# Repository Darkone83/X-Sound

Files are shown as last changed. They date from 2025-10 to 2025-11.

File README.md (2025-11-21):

<p align="center">
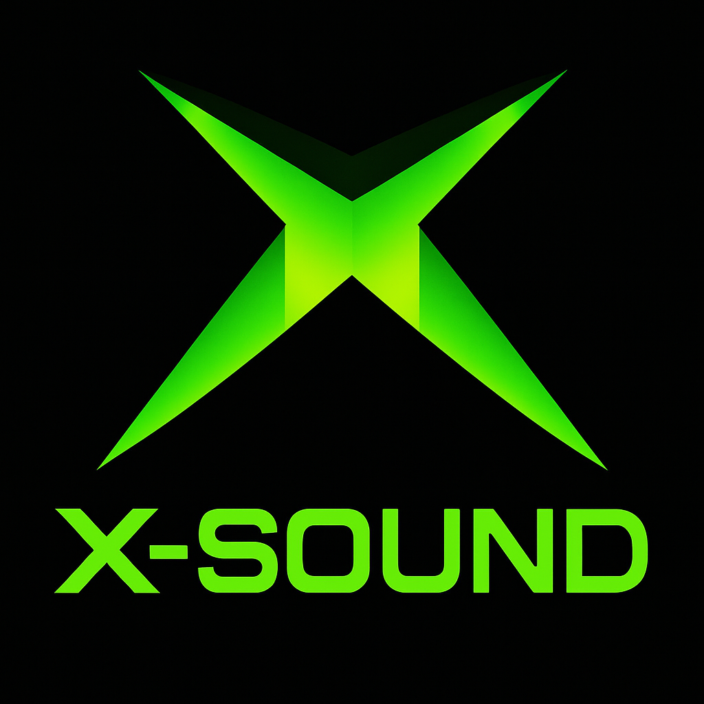
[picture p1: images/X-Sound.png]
  
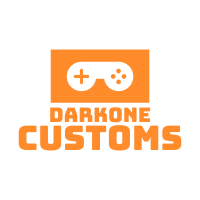
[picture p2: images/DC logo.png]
  
</p>

<p align="center">
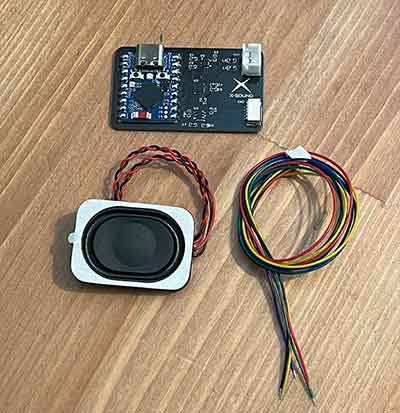
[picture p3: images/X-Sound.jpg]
  
</p>



# X-Sound

Ever wanted an Xbox startup sound? X-Sound brings it to the OG XBOX, with a compact ESP32-S3 module that adds custom **boot** and **eject** sounds to your original Xbox. No more silent power-ups – now you get that nostalgic audio experience with modern web-based control.

Built by **Darkone83 / Darkone Customs**.

---

## What it does

**Plays the sounds you remember**
- Triggers `/boot.mp3` automatically when you power on
- Plays `/eject.mp3` when you hit the eject button
- Works with .mp3 files (96-128kbps, 44.1kHz mono, keep them under 30 seconds)

**Easy file management through your browser**
- Upload, delete, and test audio files from any device on your network
- Built-in volume control and playback testing
- No need to fiddle with SD cards or complex file transfers

**Smart Wi-Fi setup**
- First boot creates a setup network you connect to
- Configure once, then it automatically connects to your home Wi-Fi
- Access everything at `http://xsound.local`

**Clean installation**
- Uses Xbox's own 3.3V rail to control power switching
- Only draws power when your Xbox is actually on

---

## Get one

Full kit available at: <a href="https://www.darkonecustoms.com/store/p/x-sound">Darkone Customs</a>

---

## Building the firmware

#### Web Flasher: 

Want to customize or build your own? Here's what you need:

1. Grab the project files and open in Arduino IDE
2. Install the libraries listed below
3. Set up your board configuration (see settings table)
4. Upload `X-Sound.ino` to your ESP32-S3
5. Connect to the `X-Sound-Setup` network that appears
6. Enter your home Wi-Fi details
7. Once it reboots, go to `http://xsound.local`
8. Upload your `boot.mp3` and `eject.mp3` files

---

## Libraries you'll need

Install these through the Arduino IDE Library Manager:

- **ESP Async WebServer** (me-no-dev)
- **AsyncTCP** (me-no-dev)
- **ESP8266Audio** (Earle Philhower)

> Note: Make sure you're using `AudioFileSourceFS` instead of `AudioFileSourceSPIFFS` for ESP32 compatibility.

---

## Arduino IDE setup

| Setting | Value |
|---|---|
| **Board** | ESP32S3 Dev Module |
| **Upload Speed** | 921600 |
| **Flash Freq** | 80 MHz |
| **PSRAM** | Disabled |
| **Partition Scheme** | 1.2 MB App / 1.5 MB SPIFFS |
| **Core Version** | ESP32 3.0.7 (Recommended) |

---

## Connecting to your Xbox

### Xbox connector pinout (CN2)
| Pin | What it is |
|---|---|
| 1 | 5V |
| 2 | GND |
| 3 | X3V3 (3.3V detection) |
| 4 | GND |
| 5 | EJECT (goes low when pressed) |

---

## Installation points

> ⚠️ **Unplug your Xbox first!**

Here's where to tap into your Xbox motherboard:

**Ground (GND):** Any solid ground point works. The LPC header ground is convenient, or the DVD connector ground.

**5V:** Grab this from the LPC connector or the DVD power plug's 5V line.

**3.3V:** Connect to the 3.3V rail on the LPC connector (pin 3). This tells X-Sound when your Xbox is actually powered up.

**EJECT:** Tap into the eject signal from the front panel connector or find the trace on the mainboard.

Keep your wires short and neat. Twisted pairs help reduce interference if you're having audio issues.

---

## Getting connected

**First time setup:**
1. Power up and look for the `X-Sound-Setup` Wi-Fi network
2. Connect with your phone or computer
3. The setup page should open automatically (or go to `192.168.4.1`)
4. Enter your home Wi-Fi name and password
5. Hit save and wait for it to reboot

**Normal use:**
- Visit `http://xsound.local` from any device on your network
- Use the File Manager to upload your sounds
- Test playback and adjust volume as needed

---

## When things go wrong

| Problem | Try this |
|---|---|
| **Can't reach the web page** | Check that you're going to `xsound.local` and look at the LED: Green = connected, Red = no Wi-Fi |
| **No sound plays** | Make sure you have `/boot.mp3` and `/eject.mp3` uploaded and they're proper MP3 files |
| **Audio sounds terrible** | Turn down the volume or re-encode your files as 44.1kHz mono at 128kbps |
| **Eject button doesn't work** | Double-check your GPIO9 connection and make sure the Xbox signal is wired correctly |
| **LED blinks red rapidly** | File playback error - check that your MP3 is 96-128kbps, 44.1kHz mono, under 30 seconds |
| **Won't power on at all** | Verify the 3.3V connection. Without it, X-Sound won't boot |

---

## Credits

**Concept:** Darkone83 / LD50 II   
**Hardware design:** Darkone83  
**Firmware:** Darkone83  
**Libraries we couldn't live without:**
- ESP8266Audio by Earle Philhower
- ESP Async WebServer / AsyncTCP by me-no-dev

---

## How it all works

```
┌────────────────────────────────────────────────────┐
│                   ESP32-S3 ZERO                    │
│                                                    │
│  GPIO12 ────────► BCLK ───────► MAX98357A (I²S AMP)│
│  GPIO11 ────────► LRCLK ─────►                     │
│  GPIO10 ────────► DOUT ──────► DIN                 │
│  GPIO9  ◄───────► EJECT (Xbox CN2 Pin 5)           │
│                                                    │
│  3.3V (out) ─────► TPS22918 EN (ON pin)            │
│  5V (in)  ───────► TPS22918 VIN                    │
│  5VEN (switched) ─► MAX98357A VDD                  │
│                                                    │
│  SPIFFS: /boot.mp3 /eject.mp3                      │
│  Web: http://xsound.local/files                    │
└────────────────────────────────────────────────────┘

   CN2 (Xbox Front Panel)
   ┌─────┬────────────┐
   │ 1   │ 5V         │
   │ 2   │ GND        │
   │ 3   │ X3V3 Detect│
   │ 4   │ GND        │
   │ 5   │ EJECT      │
   └─────┴────────────┘
```

---

**X-Sound** — Because your Xbox deserves to sound as good as it looks.  
© 2025 **Darkone83 / Darkone Customs**

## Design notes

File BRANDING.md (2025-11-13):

# X-Sound Branding Requirements  
**Darkone Customs / Darkone83**

This document defines the branding rules for all derivatives, forks, and
redistribution of the X-Sound hardware and software.

---

## 1. Branding Must Remain Intact
All Darkone Customs and Darkone83 branding MUST remain untouched in:

- PCB silkscreens  
- Schematics  
- 3D models  
- Firmware UI elements  
- Documentation  
- Images/renderings  
- Marketing material derived from the project  

Branding includes (but is not limited to):

- "Darkone83"
- "Darkone Customs"
- "Team Resurgent"
- Logos, icons, and symbol marks used in PCB art

Removal, modification, shrinking, obscuring, or overwriting of these elements
is **not permitted**.

---

## 2. Required Attribution
Any forks, derivatives, or commercial uses **must clearly state**:

**"Original Design by Darkone83 / Darkone Customs"**

This must appear in:

- README files  
- Product listings (if sold)  
- Printed or digital documentation  
- Any derivative hardware silkscreens  

---

## 3. Additional Branding (Allowed)
You may add:

- Your own maker mark  
- Your logo  
- Version codes  
- Batch identifiers  
- Assembly information  

…as long as the original branding remains **visible and unaltered**.

---

## 4. Use of Name and Logos
You *may not* imply that Darkone Customs endorses or supports derivative works.

You *may not* use the logos or branding for unrelated projects unless granted
permission.

---

## 5. Approved Files
Official versions of logos, silkscreen assets, and identifiers will be included
under:

```
/branding/
```

You must use the provided official versions if they exist.

---

## 6. Reporting Violations
If you find a fork, derivative, or commercial listing violating these rules,
open an Issue on the repository with links and details.

---

This branding policy protects the identity and authorship of the X-Sound project
and all associated Darkone Customs work.

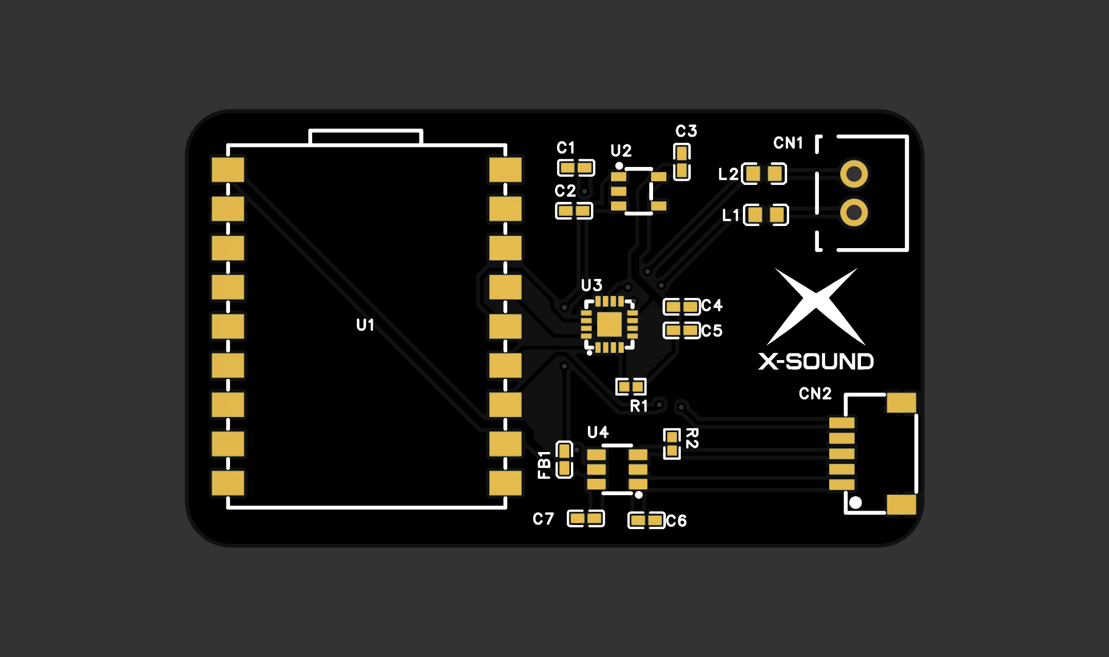
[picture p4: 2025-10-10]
images/PCB_Front.png

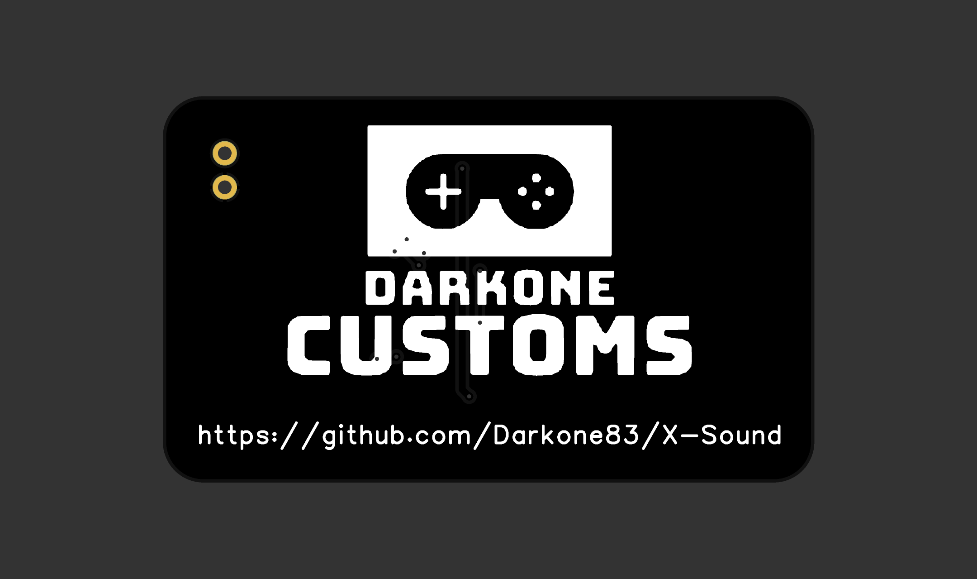
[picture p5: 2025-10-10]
images/PCB_Back.png

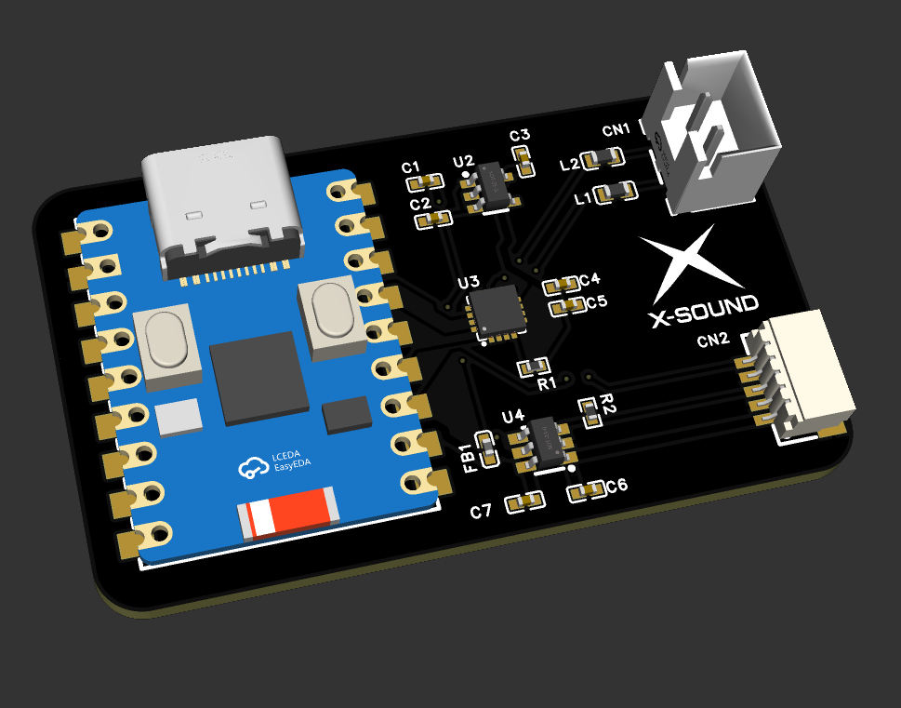
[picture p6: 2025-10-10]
images/3D Front.png

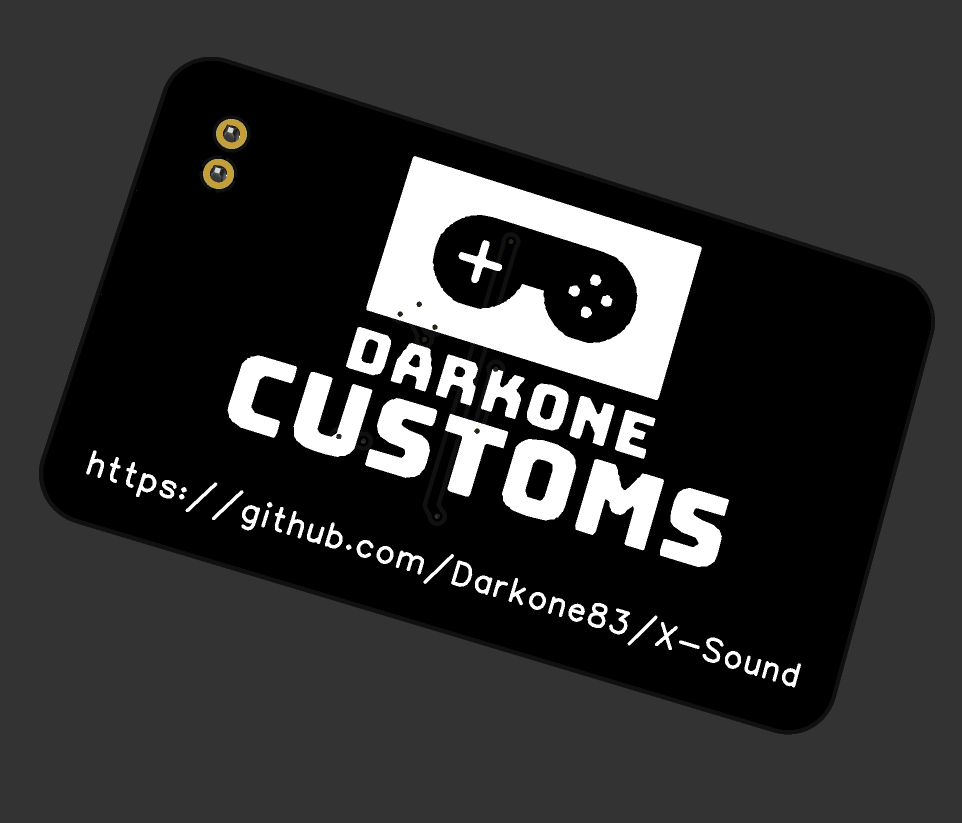
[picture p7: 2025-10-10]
images/3D Back.png

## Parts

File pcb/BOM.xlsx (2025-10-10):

No. | Quantity | Comment | Designator | Footprint | Value | Manufacturer Part | Manufacturer | Supplier Part | Supplier
1 | 2 | 10uF | C1,C4 | C0402 | 10uF | CL05A106MQ5NUNC | SAMSUNG(三星) | C15525 | LCSC
2 | 4 | 1uF | C2,C3,C6,C7 | C0402 | 1uF | CL05A105KO5NNNC | SAMSUNG(三星) | C29266 | LCSC
3 | 1 | 100nF | C5 | C0402 | 100nF | CC0402KRX7R5BB104 | YAGEO(国巨) | C541406 | LCSC
4 | 1 | B2B-XH-A(LF)(SN) | CN1 | CONN-TH_B2B-XH-A-LF-SN |  | B2B-XH-A(LF)(SN) | JST | C158012 | LCSC
5 | 1 | XDWF-0910-05P | CN2 | CONN-SMD_XDWF-0910-05P |  | XDWF-0910-05P | LX(连欣科技) | C7527620 | LCSC
6 | 1 | CBM100505U201T | FB1 | L0402 |  | CBM100505U201T | FH(风华) | C394402 | LCSC
7 | 2 | BLM18SG331TN1D | L1,L2 | L0603 |  | BLM18SG331TN1D | muRata(村田) | C88989 | LCSC
8 | 1 | 680kΩ | R1 | R0402 | 680kΩ | FRC0402F6803TS | FOJAN(富捷) | C2909377 | LCSC
9 | 1 | 100kΩ | R2 | R0402 | 100kΩ | RC0402FR-07100KL | YAGEO(国巨) | C60491 | LCSC
10 | 1 | ESP32-S3-Zero | U1 | COMM-SMD_18P-P2.54-L23.5-W18.0-TL |  | ESP32-S3-Zero |  | C9900152785 | LCSC
11 | 1 | XC6227C331MR-G | U2 | SOT-25-5 |  | XC6227C331MR-G | TOREX(特瑞仕) | C216640 | LCSC
12 | 1 | MAX98357AETE+T | U3 | TQFN-16_L3.0-W3.0-P0.50-BL-EP1.5 |  | MAX98357AETE+T | ADI(亚德诺)/MAXIM(美信) | C910544 | LCSC
13 | 1 | TPS22918DBVR | U4 | SOT-23-6_L2.9-W1.6-P0.95-LS2.8-BR |  | TPS22918DBVR | TI(德州仪器) | C131941 | LCSC

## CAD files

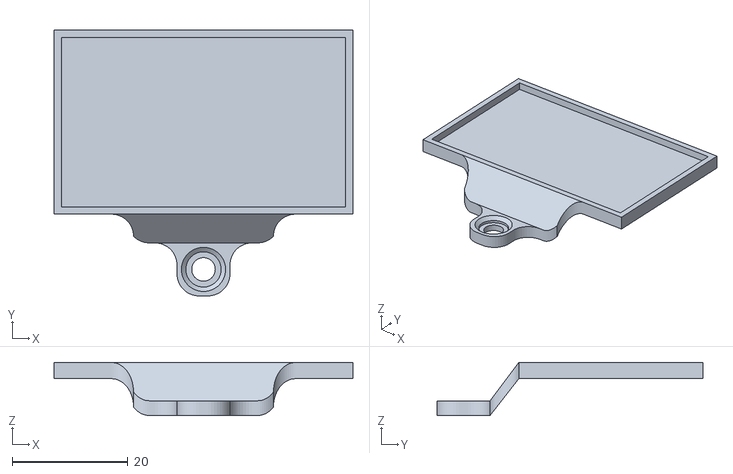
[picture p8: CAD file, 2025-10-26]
STL/X Sound Mount v1.stl
51.6 x 45.8 x 9.14

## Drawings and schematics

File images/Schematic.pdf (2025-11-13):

# IO7 10 IO8 11 IO9 12 IO10 13 IO11 14 IO12 15 IO13 16 RX 17 TX 18

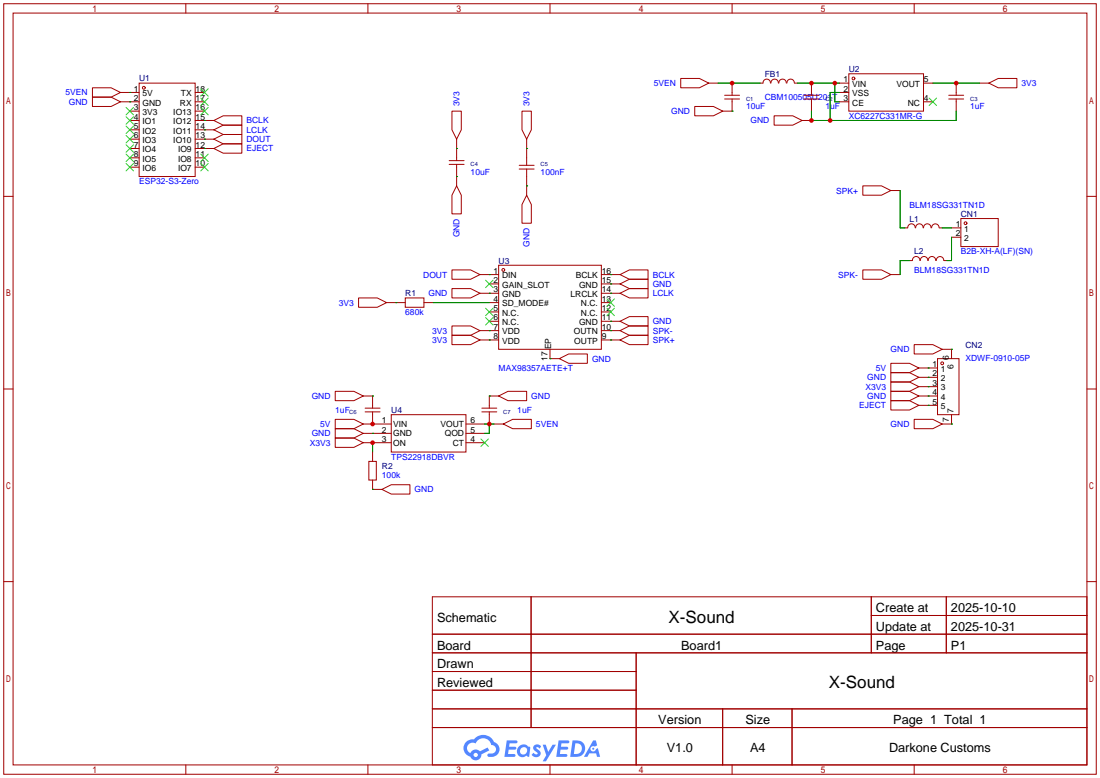
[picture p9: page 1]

OUTN 10 GND 11 N.C. 12 N.C. 13 LRCLK 14 GND 15 BCLK 16

Schematic | X-Sound | Create at | 2025-10-10

Update at | 2025-10-31

Board | Board1 | Page | P1
Drawn | | X-Sound
Reviewed

Version | Size | Page 1 Total 1
V1.0 | A4 | Darkone Customs

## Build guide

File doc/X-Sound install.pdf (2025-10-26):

# X-Sound Usage and Installation

Hardware installation:

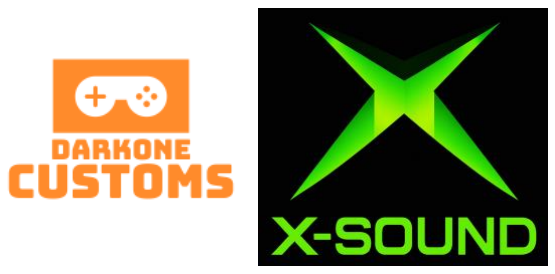
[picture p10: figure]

X-Sound requires the following connections:

5V
GND
3.3V
Eject

3 of the 4 signals can be tapped from the XBOX’s LPC header for ease of installation. As wiring harness colors may not be standardized here is the pinout of CN2:

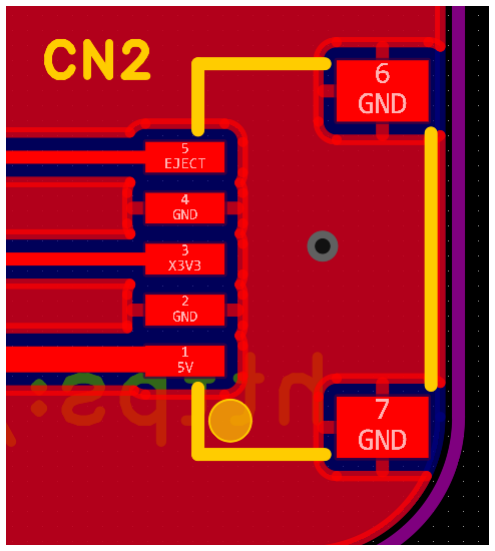
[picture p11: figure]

XBOX LPC header:

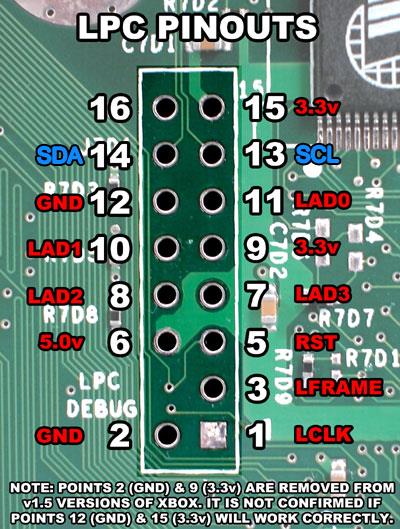
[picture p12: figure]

For eject, it's recommended to tap this from the back of the XBOX front panel, as it has ample routing and is easiest to access>

Eject Solder Point:

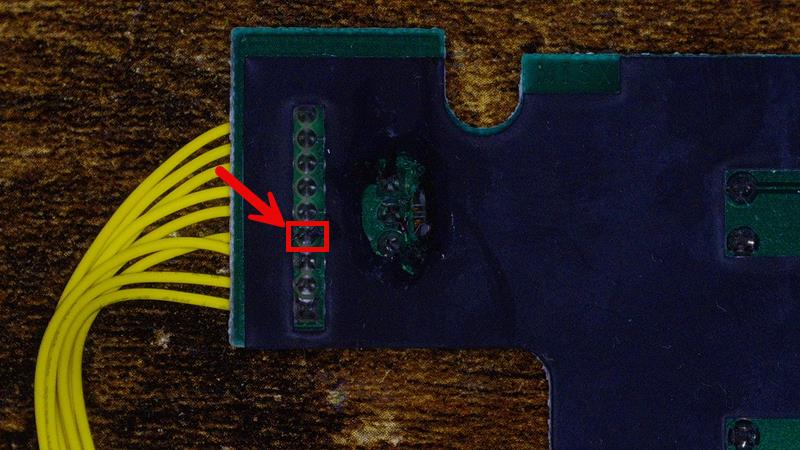
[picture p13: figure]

Example Routing:

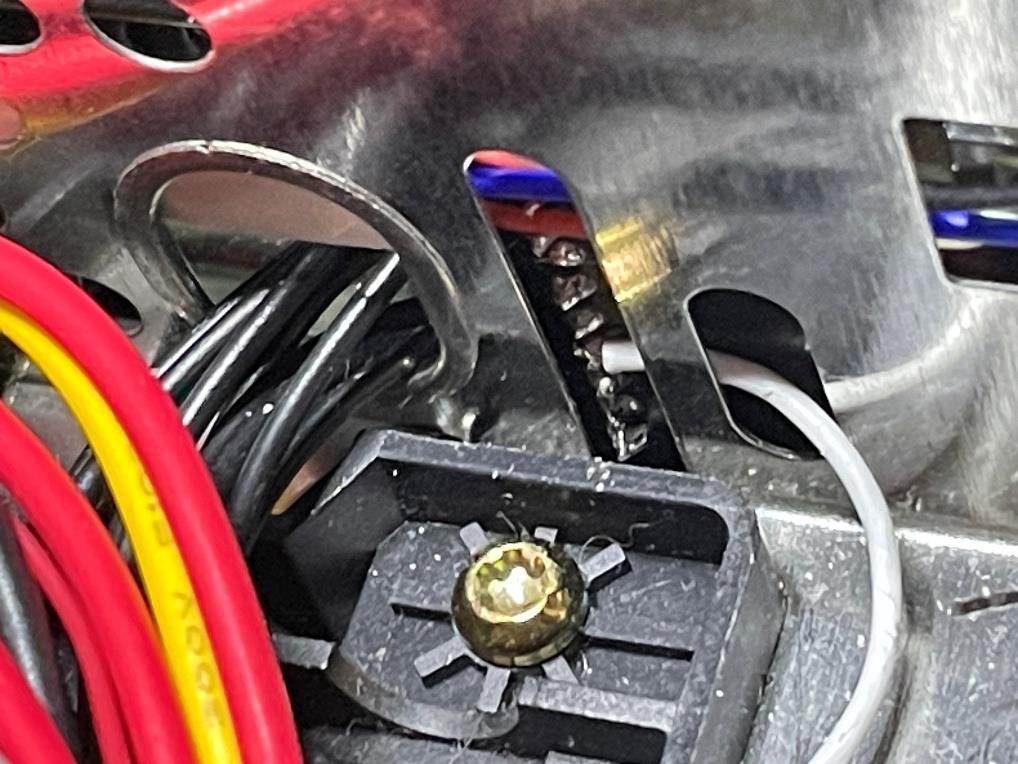
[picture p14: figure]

Finally connect your speaker

Recommended placement for X-Sound can vary by the installation; you can download the STL from the GitHub (https://github.com/Darkone83/X-Sound/blob/main/STL/X%20Sound%20Mount%20v1.stl) repo and opt for a mounted installation (recommended) or mount it to the inside of your XBOX. Ideally, you want the speaker and X-Sound mounted to non-conductive surfaces.

First Boot / Setup:

After installation on first power-up, X-Sound’s LED will go white, then blink purple for a second, then go to flashing red. Don’t panic, this is normal and simply means boot.mp3 is not found. To get started, connect X-Sound to choose a WiFi network ( WiFi is not strictly required but is recommended).

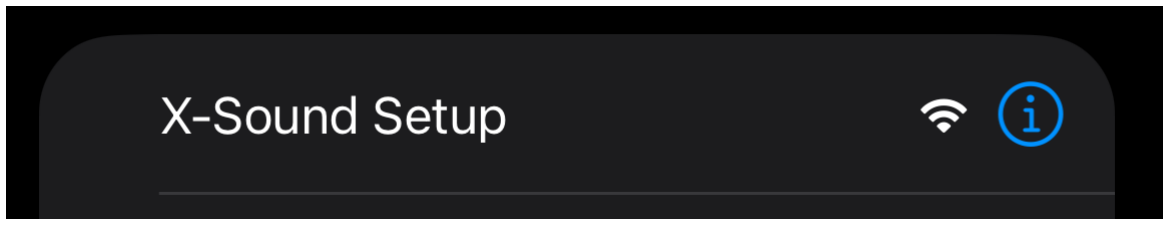
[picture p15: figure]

Once connected, you will be at the Configuration screen. Start by connecting to your WiFi network of choice

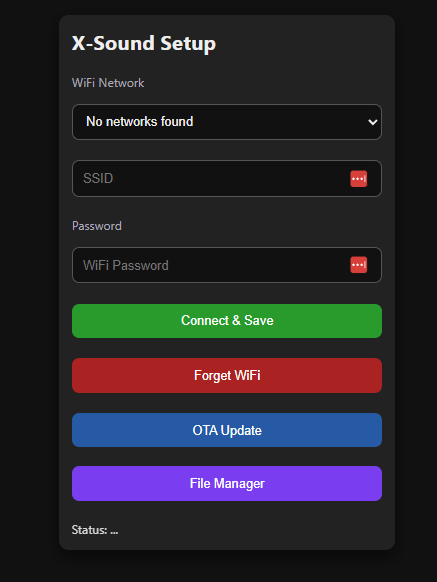
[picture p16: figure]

Once you have selected your network, click on Connect & Save. Once connected your X-Sound is accessible from http://xsound.local.

Sound Configuration:

X-Sound at the time of writing supports .mp3 files. Its suggested your files are 96 – 128 kbps and in mono, stereo can be put on X-Sound but X-Sound only currently supports mono playback. For your boot sounds its recommended to keep it to less than 1 minute as you will only have 1.5mb for both boot and eject sounds.

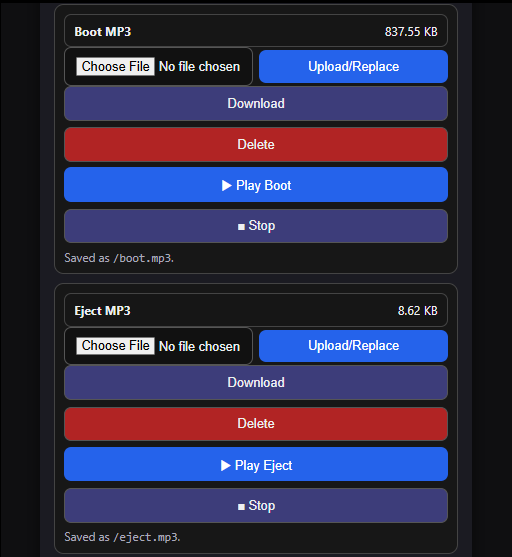
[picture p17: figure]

For both boot and eject, the process is exactly the same: Choose your file, then click Upload/Replace. X-Sound will rename the file for you, so no need to change the name beforehand.

The UI also gives you a few additional file management features such as: Downloading your currently saved sound, deleting your sound, playing your sound from the WebUI, and stopping your Sound from the WebUI.

Setting Volume:

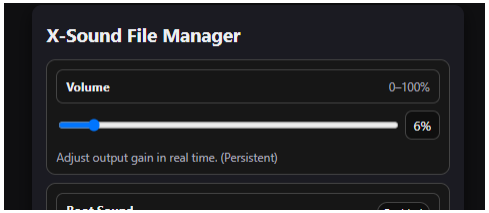
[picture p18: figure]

Simply drag the slider to your desired volume level X-Sound will remember your setting and apply it instantly. It will also remember this for every boot.

Additional options:

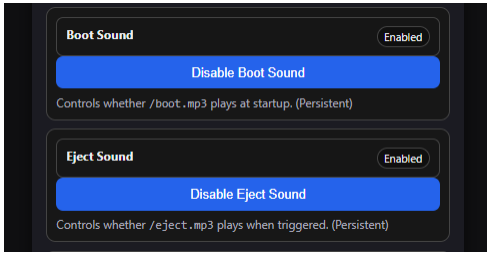
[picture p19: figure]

X-Sound does give you the ability to disable boot and eject so theirs no need to disconnect anything.

LED Statuses:

X-Sound has a few different LED statuses. Here's what they mean.

White = Booting
Green = Connected to WiFi
Red (solid) = Unable to Connect to WiFi
Purple (blinking) = WiFi portal mode
Magenta (blinking) = Currently playing a sound (will trigger on boot or eject) Red (fast flash) = No boot or eject.mp3 found

Troubleshooting:

Issue | Solution
No web page | Retry http://xsound.local or check LED status — Green = Wi-Fi connected, Red = no Wi-Fi
No audio | Verify /boot.mp3 & /eject.mp3 exist and are valid MP3s
Distortion | Lower volume or re-encode audio as 44.1 kHz mono @128 kbps
Eject not working | Check GPIO9 pull-up and Xbox signal polarity
Fast blinking red LED | Error with file playback, ensure file is the proper format (MP3 96 -128kpbs 44.1kHz mono under 30s)

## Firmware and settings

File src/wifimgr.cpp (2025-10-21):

#include "wifimgr.h"
#include <WiFi.h>
#include <ESPAsyncWebServer.h>
#include <Preferences.h>
#include <DNSServer.h>
#include "led_stat.h"
#include <vector>
#include <algorithm>
#include "esp_wifi.h"
#include <Update.h>  // OTA

// Single global server used by the whole project
static AsyncWebServer server(80);

namespace WiFiMgr {

static String ssid, password;
static Preferences prefs;
static DNSServer dnsServer;
static std::vector<String> lastScanResults;

enum class State { IDLE, CONNECTING, CONNECTED, PORTAL };
static State state = State::IDLE;

static int connectAttempts = 0;
static const int maxAttempts = 10;  // Reduced from 50 for faster fallback
static unsigned long lastAttempt = 0;
static unsigned long retryDelay = 3000;  // Increased from 2500ms

// Ensure portal routes are only added once (so we don't need server.reset()).
static bool portalRoutesAdded = false;
static bool serverStarted = false;

static bool dnsServerStarted = false;

AsyncWebServer& getServer() {
  return server;
}

// ---------------- WiFi cred storage ----------------
static void loadCreds() {
  prefs.begin("wifi", true);
  ssid = prefs.getString("ssid", "");
  password = prefs.getString("pass", "");
  prefs.end();
}

static void saveCreds(const String& s, const String& p) {
  prefs.begin("wifi", false);
  prefs.putString("ssid", s);
  prefs.putString("pass", p);
  prefs.end();
}

static void clearCreds() {
  prefs.begin("wifi", false);
  prefs.remove("ssid");
  prefs.remove("pass");
  prefs.end();
}

// --------------- AP/Portal helpers -----------------
static void setAPConfig() {
  WiFi.softAPConfig(
    IPAddress(192, 168, 4, 1),
    IPAddress(192, 168, 4, 1),
    IPAddress(255, 255, 255, 0)
  );
}

// ===== OTA HTML (progress + client-driven reboot) =====
static const char OTA_PAGE[] PROGMEM = R"html(
<!DOCTYPE html><html><head><meta charset="utf-8">
<meta name="viewport" content="width=device-width,initial-scale=1,viewport-fit=cover">
<title>OTA Update</title>
<style>
  :root{--bg:#111;--card:#222;--ink:#EEE;--mut:#AAB;--btn:#2563eb;--ok:#2ea043;--err:#d32}
  *{box-sizing:border-box} html,body{height:100%}
  body{background:var(--bg);color:var(--ink);font-family:system-ui,Segoe UI,Roboto,Arial;margin:0}
  .wrap{min-height:100%;display:flex;align-items:center;justify-content:center;padding:env(safe-area-inset-top) 12px env(safe-area-inset-bottom)}
  .box{width:100%;max-width:520px;margin:16px auto;background:var(--card);padding:18px 16px;border-radius:12px;box-shadow:0 8px 20px #0008}
  h2{margin:0 0 12px}
  .row{display:grid;grid-template-columns:1fr;gap:10px}
  input[type=file],button{width:100%;margin:.25rem 0;padding:.7rem .8rem;border-radius:9px;border:1px solid #555;background:#111;color:var(--ink);font-size:1rem}
  button{background:var(--btn);border:0;color:#fff;cursor:pointer}
  .status{margin-top:10px;color:var(--mut)}
  .bar{height:12px;background:#0c1222;border:1px solid #334;border-radius:999px;overflow:hidden}
  .fill{height:100%;width:0%}
  .ok{background:linear-gradient(90deg,#28a745,#3ddc84)}
  .up{background:linear-gradient(90deg,#4c7cff,#7aa4ff)}
  .err{background:linear-gradient(90deg,#d32,#f55)}
  .msg{margin-top:8px;font-size:.95rem}
</style></head>
<body>
<div class="wrap">
  <div class="box">
    <h2>OTA Update</h2>
    <div class="row">
      <input id="fw" type="file" accept=".bin,.bin.gz">
      <button id="go">Upload & Flash</button>
      <div class="bar"><div id="fill" class="fill up"></div></div>
      <div id="msg" class="msg">Select a firmware <code>.bin</code> (or <code>.bin.gz</code>) and click "Upload & Flash".</div>
      <div class="row">
        <button onclick="location.href='/'">⟵ Back to WiFi Setup</button>
        <button onclick="location.href='/files'">File Manager</button>
        <button onclick="reboot()" style="background:#a22">Reboot</button>
      </div>
      <div id="status" class="status"></div>
    </div>
  </div>
</div>
<script>
(function(){
  const fw   = document.getElementById('fw');
  const btn  = document.getElementById('go');
  const fill = document.getElementById('fill');
  const msg  = document.getElementById('msg');
  const status = document.getElementById('status');

  function setFill(p, cls){
    fill.style.width = (Math.max(0,Math.min(100,p))|0) + '%';
    fill.className = 'fill ' + (cls||'up');
  }
  function reboot(){
    fetch('/reboot',{method:'POST'}).catch(()=>0);
    setTimeout(()=>location.reload(), 2500);
  }
  function pingUntilUp(path, cb){
    let tries = 0;
    const t = setInterval(()=>{
      fetch(path, {cache:'no-store'}).then(r=>{ if (r.ok) { clearInterval(t); cb(true); } })
      .catch(()=>{});
      if (++tries > 180) { clearInterval(t); cb(false); }
    }, 1000);
  }

  btn.onclick = function(){
    const f = fw.files && fw.files[0];
    if(!f){ msg.textContent = 'Please select a firmware file first.'; return; }

    msg.textContent = 'Uploading...';
    status.textContent = '';
    setFill(0, 'up');

    const xhr = new XMLHttpRequest();
    xhr.open('POST', '/ota', true);
    xhr.responseType = 'text';

    xhr.upload.onprogress = function(ev){
      if (ev.lengthComputable) {
        const pc = ev.total ? (ev.loaded * 100 / ev.total) : 0;
        setFill(pc, 'up');
      }
    };

    xhr.onerror = function(){
      setFill(100, 'err');
      msg.textContent = 'Upload failed (network error).';
    };

    xhr.onload = function(){
      let ok = xhr.status>=200 && xhr.status<300;
      try { const j = JSON.parse(xhr.responseText||'{}'); ok = ok && !!j.ok; } catch(e){}
      if (ok) {
        setFill(100, 'ok');
        msg.textContent = 'Flashed OK. Rebooting device...';
        status.textContent = 'Waiting for device to come back online...';
        fetch('/reboot',{method:'POST'}).catch(()=>0);
        pingUntilUp('/ping', function(up){
          status.textContent = up ? 'Device is back online. You may open File Manager.' :
                                    'Device did not respond in time. Power-cycle if needed.';
        });
      } else {
        setFill(100, 'err');
        msg.textContent = 'Flash failed.';
        status.textContent = xhr.responseText || ('HTTP '+xhr.status);
      }
    };

    const form = new FormData();
    form.append('firmware', f, f.name);
    xhr.send(form);
  };

  window.reboot = reboot;
})();
</script>
</body></html>
)html";

// ===== OTA route registration =====
static void registerOTARoutes() {
  // Optional firmware info
  server.on("/fw", HTTP_GET, [](AsyncWebServerRequest* req){
    String v = String("TypeD/") + String(__DATE__) + " " + String(__TIME__);
    req->send(200, "text/plain", v);
  });

  // OTA page
  server.on("/ota", HTTP_GET, [](AsyncWebServerRequest* req){
    req->send_P(200, "text/html", OTA_PAGE);
  });

  // OTA upload/flash (streamed), JSON reply; client triggers /reboot
  server.on(
    "/ota",
    HTTP_POST,
    [](AsyncWebServerRequest* request){
      const bool ok = !Update.hasError();
      if (ok) {
        String msg = "{\"ok\":true,\"bytes\":" + String(Update.progress()) + "}";
        request->send(200, "application/json", msg);
        Serial.println("[OTA] Update uploaded OK; client will reboot device.");
      } else {
        request->send(500, "application/json", "{\"ok\":false}");
        Serial.println("[OTA] Update failed.");
      }
    },
    [](AsyncWebServerRequest* request, String filename, size_t index, uint8_t* data, size_t len, bool final){
      if (index == 0) {
        Serial.printf("[OTA] Starting: %s\n", filename.c_str());
        if (!Update.begin(UPDATE_SIZE_UNKNOWN)) {
          Update.printError(Serial);
        }
      }
      if (len) {
        if (Update.write(data, len) != len) {
          Update.printError(Serial);
        }
      }
      if (final) {
        if (!Update.end(true)) {
          Update.printError(Serial);
        } else {
          Serial.printf("[OTA] Finished: %u bytes\n", (unsigned)(index + len));
        }
      }
    }
  );

  // Reboot endpoint (client calls this after success)
  server.on("/reboot", HTTP_POST, [](AsyncWebServerRequest* req){
    req->send(200, "text/plain", "Rebooting...");
    Serial.println("[OTA] Reboot requested");
    auto t = millis() + 300; while (millis() < t) { delay(1); }
    ESP.restart();
  });
  server.on("/reboot", HTTP_GET, [](AsyncWebServerRequest* req){
    req->send(200, "text/plain", "Rebooting...");
    Serial.println("[OTA] Reboot requested (GET)");
    auto t = millis() + 300; while (millis() < t) { delay(1); }
    ESP.restart();
  });
}

static void addPortalRoutesOnce() {
  if (portalRoutesAdded) return;
  portalRoutesAdded = true;

  // Small ping endpoint we can use to probe device reachability
  server.on("/ping", HTTP_GET, [](AsyncWebServerRequest *request){
    AsyncWebServerResponse* resp = request->beginResponse(200, "text/plain", "ok");
    resp->addHeader("Cache-Control", "no-store");
    request->send(resp);
  });

  // ⬇️ Add OTA routes (available in AP/STA)
  registerOTARoutes();

  // ---------- Portal UI ----------
  server.on("/", HTTP_GET, [](AsyncWebServerRequest *request){
    String page = R"HTML(
<!DOCTYPE html>
<html>
<head>
  <title>WiFi Setup</title>
  <meta name="viewport" content="width=device-width,initial-scale=1,viewport-fit=cover">
  <style>
    :root{--bg:#111;--card:#222;--ink:#EEE;--mut:#AAB;--pri:#299a2c;--warn:#a22;--link:#9ec1ff}
    *{box-sizing:border-box}
    html,body{height:100%}
    body {background:var(--bg);color:var(--ink);font-family:system-ui,Segoe UI,Roboto,Arial;margin:0}
    .wrap{min-height:100%;display:flex;align-items:center;justify-content:center;padding:env(safe-area-inset-top) 12px env(safe-area-inset-bottom)}
    .container {width:100%;max-width:420px;margin:16px auto;background:var(--card);padding:16px;border-radius:12px;box-shadow:0 8px 20px #0008;}
    h1 {margin:0 0 .6em; font-size:1.6em}
    label{display:block;margin-top:8px;color:var(--mut);font-size:.95em}
    input,select,button {width:100%;margin:.5em 0;padding:.75em .8em;font-size:1em;border-radius:9px;border:1px solid #555;background:#111;color:var(--ink)}
    button{cursor:pointer}
    .btn-primary {background:var(--pri);border:0;color:white}
    .btn-danger {background:var(--warn);border:0;color:white}
    .btn-ota {background:#265aa5;border:0;color:white}
    .btn-config {background:#7a3ef0;border:0;color:white}
    .row {display:grid;grid-template-columns:1fr;gap:.6em}
    .status {margin-top:8px;opacity:.9;font-size:.95em}
    .links{display:flex;gap:8px;flex-wrap:wrap}
    .links a{color:var(--link);text-decoration:none}
  </style>
</head>
<body>
  <div class="wrap">
  <div class="container">
    <h1>X-Sound Setup</h1>
    <div class="row">
      <label>WiFi Network</label>
      <select id="ssidDropdown">
        <option value="">Scanning...</option>
      </select>
      <input type="text" id="ssid" placeholder="SSID">
      <label>Password</label>
      <input type="password" id="pass" placeholder="WiFi Password">
      <button type="button" onclick="save()" class="btn-primary">Connect & Save</button>
      <button type="button" onclick="forget()" class="btn-danger">Forget WiFi</button>
      <div class="links">
        <button type="button" onclick="window.location='/ota'" class="btn-ota">OTA Update</button>
        <button type="button" onclick="window.location='/files'" class="btn-config">File Manager</button>
      </div>
      <div class="status" id="status">Status: ...</div>
    </div>
  </div>
  </div>
<script>
  function scan() {
    fetch('/scan',{cache:'no-store'}).then(r => r.json()).then(list => {
      let dd = document.getElementById('ssidDropdown');
      dd.innerHTML = '';
      let def = document.createElement('option');
      def.value = '';
      def.text = list.length ? 'Please select a network' : 'No networks found';
      dd.appendChild(def);
      list.forEach(name => {
        let opt = document.createElement('option');
        opt.value = name;
        opt.text = name;
        dd.appendChild(opt);
      });
      dd.onchange = function(){ document.getElementById('ssid').value = dd.value; };
    }).catch(() => {
      let dd = document.getElementById('ssidDropdown');
      dd.innerHTML = '';
      let opt = document.createElement('option');
      opt.value = '';
      opt.text = 'Scan failed';
      dd.appendChild(opt);
    });
  }
  setInterval(scan, 3000);
  window.onload = scan;

  function save() {
    let ssid = document.getElementById('ssid').value;
    let pass = document.getElementById('pass').value;
    fetch('/save',{
      method:'POST',
      headers:{'Content-Type':'application/json','Cache-Control':'no-store'},
      body:JSON.stringify({ssid:ssid,pass:pass})
    }).then(r=>r.text()).then(t=>{ document.getElementById('status').innerText=t; }).catch(()=>{
      document.getElementById('status').innerText='Error sending credentials';
    });
  }
  function forget() {
    fetch('/forget',{cache:'no-store'}).then(r=>r.text()).then(t=>{
      document.getElementById('status').innerText=t;
      document.getElementById('ssid').value='';
      document.getElementById('pass').value='';
    });
  }
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
void loop() {
  // Always process DNS requests if portal is active
  if (state == State::PORTAL) {
    dnsServer.processNextRequest();
  }

  switch (state) {
    case State::CONNECTING: {
      if (WiFi.status() == WL_CONNECTED) {
        state = State::CONNECTED;
        stopPortal();  // Stop DNS server
        
        Serial.println("[WiFiMgr] WiFi connected!");
        Serial.print("[WiFiMgr] IP Address: ");
        Serial.println(WiFi.localIP());
        Serial.printf("[WiFiMgr] RSSI: %d dBm\n", WiFi.RSSI());
        
        LedStat::setStatus(LedStatus::WifiConnected);
        
        // Ensure web server is accessible
        if (!serverStarted) {
          addPortalRoutesOnce();
          server.begin();
          serverStarted = true;
        }
      } else if (millis() - lastAttempt > retryDelay) {
        connectAttempts++;
        Serial.printf("[WiFiMgr] Connection attempt %d/%d (WiFi status: %d)\n", 
                      connectAttempts, maxAttempts, WiFi.status());
        
        if (connectAttempts >= maxAttempts) {
          Serial.println("[WiFiMgr] Max connection attempts reached, will start portal");
          LedStat::setStatus(LedStatus::WifiFailed);
          
          // Give system a moment to stabilize before switching modes
          delay(500);
          
          state = State::PORTAL;
          startPortal();
        } else {
          // Retry connection
          lastAttempt = millis();
        }
      }
      break;
    }
    
    case State::CONNECTED: {
      // Monitor connection and reconnect if lost
      if (WiFi.status() != WL_CONNECTED) {
        Serial.println("[WiFiMgr] Lost connection, attempting reconnect...");
        state = State::CONNECTING;
        connectAttempts = 0;
        lastAttempt = millis();
        WiFi.begin(ssid.c_str(), password.c_str());
        LedStat::setStatus(LedStatus::Booting);
      }
      break;
    }
    
    case State::PORTAL: {
      // Portal mode - nothing special to do
      break;
    }
    
    case State::IDLE:
    default:
      break;
  }
}

void restartPortal() {
  Serial.println("[WiFiMgr] Manual portal restart requested");
  state = State::PORTAL;
  startPortal();
}

void forgetWiFi() {
  Serial.println("[WiFiMgr] Forgetting WiFi credentials");
  clearCreds();
  ssid = "";
  password = "";
  WiFi.disconnect(true);
  state = State::PORTAL;
  startPortal();
}

bool isConnected() {
  return (state == State::CONNECTED && WiFi.status() == WL_CONNECTED);
}

String getStatus() {
  if (isConnected()) {
    return "Connected to: " + ssid + " (IP: " + WiFi.localIP().toString() + ")";
  }
  if (state == State::CONNECTING) {
    return "Connecting to: " + ssid + " (attempt " + String(connectAttempts) + "/" + String(maxAttempts) + ")";
  }
  if (state == State::PORTAL) {
    return "Portal mode active";
  }
  return "Not connected";
}

} // namespace WiFiMgr

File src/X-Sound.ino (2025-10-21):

// X-Sound.ino — Waveshare ESP32-S3 integration
// - Plays /boot.mp3 once at power-up (before WiFi init)
// - Eject sound: /eject.mp3 on falling edge from Xbox EJECT line (active-LOW)
// - Keeps WiFiMgr (/ + /ota), FileMan (/files), LED status, and mDNS (xsound.local)

#include <Arduino.h>
#include <WiFi.h>
#include <ESPmDNS.h>
#include <SPIFFS.h>

#include "led_stat.h"
#include "wifimgr.h"
#include "fileman.h"
#include "audio_player.h"

// ======================== Board/Pins ========================
#ifndef I2S_PIN_BCLK
  #define I2S_PIN_BCLK  12
#endif
#ifndef I2S_PIN_LRCK
  #define I2S_PIN_LRCK  11
#endif
#ifndef I2S_PIN_DOUT
  #define I2S_PIN_DOUT  10
#endif

#ifndef PIN_EJECT_SENSE
  #define PIN_EJECT_SENSE  9
#endif

#define USE_INTERNAL_PULLUP_FOR_EJECT  1
#define EJECT_DEBOUNCE_MS  120
#define EJECT_REFIRE_MS    800

// ======================== mDNS ========================
static const char* HOSTNAME = "xsound";
static const char* FW_TAG   = "X-Sound " __DATE__ " " __TIME__;
static bool g_mdnsStarted   = false;

static void startMDNSIfNeeded() {
  if (g_mdnsStarted) return;

  WiFi.setHostname(HOSTNAME);
#ifdef CONFIG_IDF_TARGET_ESP32S3
  // On ESP32-S3 Arduino core, WiFi.setHostname sets both AP/STA hostnames.
#endif

  if (!MDNS.begin(HOSTNAME)) {
    Serial.println("[mDNS] Failed to start responder (will retry later).");
    return;
  }
  MDNS.addService("http", "tcp", 80);
  MDNS.addServiceTxt("http", "tcp", "path", "/");
  MDNS.addServiceTxt("http", "tcp", "fw", FW_TAG);
  g_mdnsStarted = true;
  Serial.printf("[mDNS] started: http://%s.local/\n", HOSTNAME);
}

static void onWiFiEvent(WiFiEvent_t event, WiFiEventInfo_t info) {
  switch (event) {
    case ARDUINO_EVENT_WIFI_STA_GOT_IP:
      Serial.printf("[mDNS] STA got IP: %s — ensure mDNS\n",
                    WiFi.localIP().toString().c_str());
      startMDNSIfNeeded();
      break;
    case ARDUINO_EVENT_WIFI_AP_START:
      Serial.println("[mDNS] AP started — ensure mDNS");
      startMDNSIfNeeded();
      break;
    default:
      break;
  }
}

// ======================== Eject ISR ========================
volatile bool g_wantEject = false;
static unsigned long g_lastEjectEdge = 0;
static unsigned long g_lastEjectFire = 0;

void IRAM_ATTR onEjectEdge() {
  const unsigned long now = millis();
  if (now - g_lastEjectEdge < EJECT_DEBOUNCE_MS) return;
  g_lastEjectEdge = now;
  if (digitalRead(PIN_EJECT_SENSE) == LOW) g_wantEject = true;
}

// ======================== Setup/Loop ========================
void setup() {
  Serial.begin(115200);
  delay(50);
  Serial.println(); 
  Serial.println(FW_TAG);

  // ---- Base services ----
  SPIFFS.begin(true);
  LedStat::begin();

  // ---- Audio before FileMan ----
  AudioPlayer::begin(I2S_PIN_BCLK, I2S_PIN_LRCK, I2S_PIN_DOUT);

  // ---- File manager (routes /files etc.) ----
  FileMan::begin();

  // ---- Eject button ----
  #if USE_INTERNAL_PULLUP_FOR_EJECT
    pinMode(PIN_EJECT_SENSE, INPUT_PULLUP);
  #else
    pinMode(PIN_EJECT_SENSE, INPUT);
  #endif
  attachInterrupt(digitalPinToInterrupt(PIN_EJECT_SENSE), onEjectEdge, FALLING);

  // ---- Play boot sound before WiFi brings up tasks ----
  delay(150);
  AudioPlayer::playBoot();

  // ---- WiFi and mDNS ----
  WiFi.onEvent(onWiFiEvent);
  WiFiMgr::begin();
  startMDNSIfNeeded();

  Serial.println("[Setup] Ready — upload /boot.mp3 and /eject.mp3 at /files.");
}

void loop() {
  AudioPlayer::loop();
  WiFiMgr::loop();
  LedStat::loop();

  // EJECT handling with refire guard
  const unsigned long now = millis();
  if (g_wantEject && (now - g_lastEjectFire > EJECT_REFIRE_MS)) {
    g_wantEject = false;
    g_lastEjectFire = now;
    AudioPlayer::playEject();
  }

  if (!g_mdnsStarted) startMDNSIfNeeded();
}

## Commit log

2025-10-10 Inital Upload
    [BOM.xlsx, PickAndPlace_X-Sound.xlsx]
2025-10-10 LED / UX additions
2025-10-16 Update
    Reworked Audioplayer, Fileman, and Wifimgr
    [X-Sound.ino, audio_player.cpp, fileman.cpp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]
2025-10-26 STL upload
    X-Sound mount by Mast3rmind777
    [X Sound Mount v1.stl]
2025-10-30 Revise EJECT connection and troubleshooting section
    Updated EJECT connection details and added troubleshooting tips for power issues.
2025-11-01 Schematic Correction
2025-11-21 Fix typo in grounding instructions for Xbox
